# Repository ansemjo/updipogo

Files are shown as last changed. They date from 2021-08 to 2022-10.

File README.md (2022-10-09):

# updipogo

This was an idea to combine a tiny board with [pogo pins](https://aliexpress.com/item/1005002667659397.html) (spring-loaded probes) on one end and a cheap [CH340N USB-to-UART chip](https://lcsc.com/product-detail/USB-ICs_WCH-Jiangsu-Qin-Heng-CH340N_C2977777.html) on the other end, to build an [UPDI programmer](https://github.com/SpenceKonde/AVR-Guidance/blob/master/UPDI/jtag2updi.md). The idea stems from a [Pnoxi AVR-ISP Pogo](https://www.tindie.com/products/pnoxi/avr-isp-pogo-pin-adapter-2x3-idc2x3-pogo-254mm/), which I use for programming older AVRs.

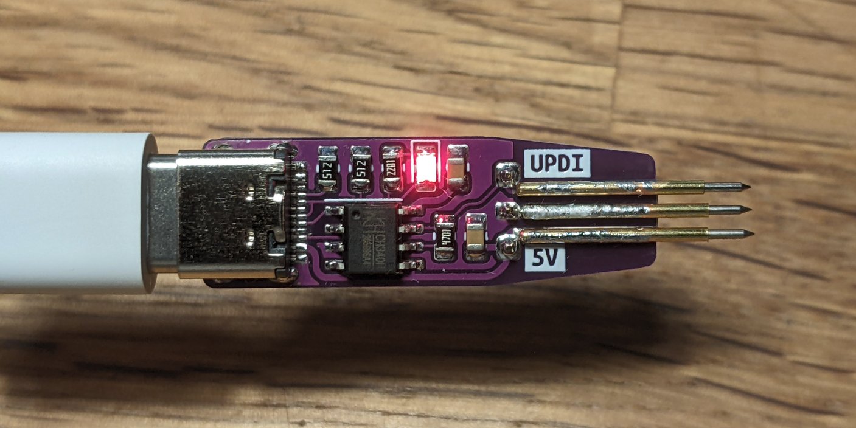
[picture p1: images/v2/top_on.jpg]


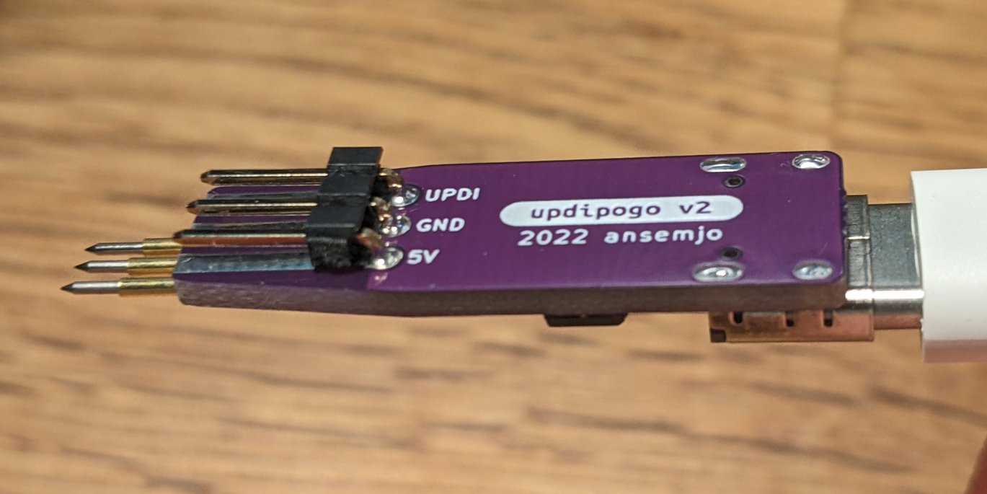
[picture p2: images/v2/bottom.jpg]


**Note:** It may be worthwhile to replace the 4.7 kΩ resistor with a diode instead. Or at least, use a smaller resistor in the range of 1–2 kΩ. [See errata](ERRATA.md#updipogo_v2).

### Programming Pads

The pogo footprint uses a somewhat dense pitch of 1.6 mm so that programming pads on future boards could require minimal space. The underside has footprints to add pins with standard 2.54 mm pitch or even a "normal" header, though.

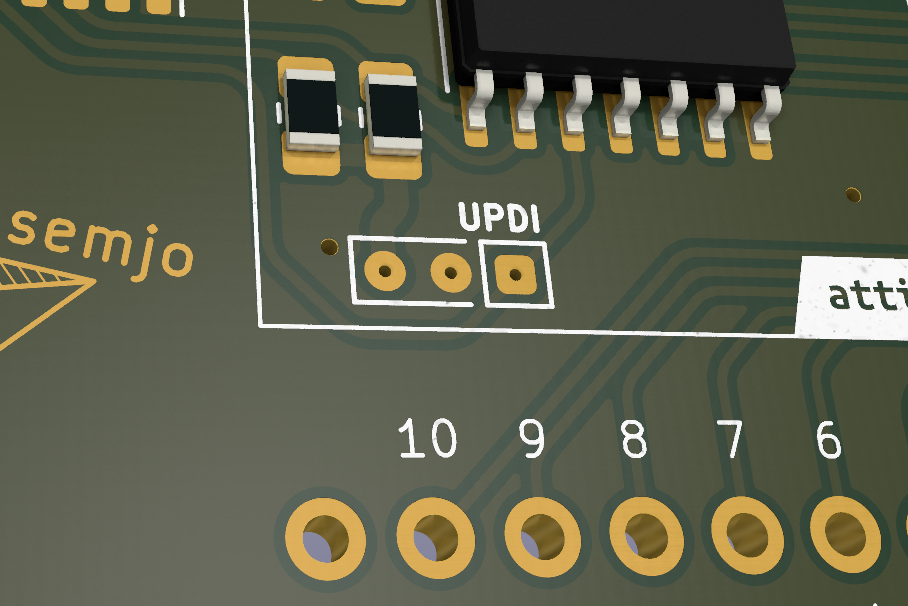
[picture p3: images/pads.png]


Add small 0.4 mm vias in the middle of the three programming pads if you can to give the spearhead tips something to fall into.

### Make Your Own

* Install [`kikit`](https://github.com/yaqwsx/KiKit)
* Run `make gerbers.zip`
* Order your PCBs
* Check the [interactive BOM](https://htmlpreview.github.io/?https://github.com/ansemjo/updipogo/blob/main/ibom.html) to see which part goes where

### Alternatives

[Stefan Wagner lists a lot of possible UPDI programmer alternatives](https://github.com/wagiminator/AVR-Programmer). Those include voltage switching, HV capable programmers and `jtag2updi`-compatible ones.

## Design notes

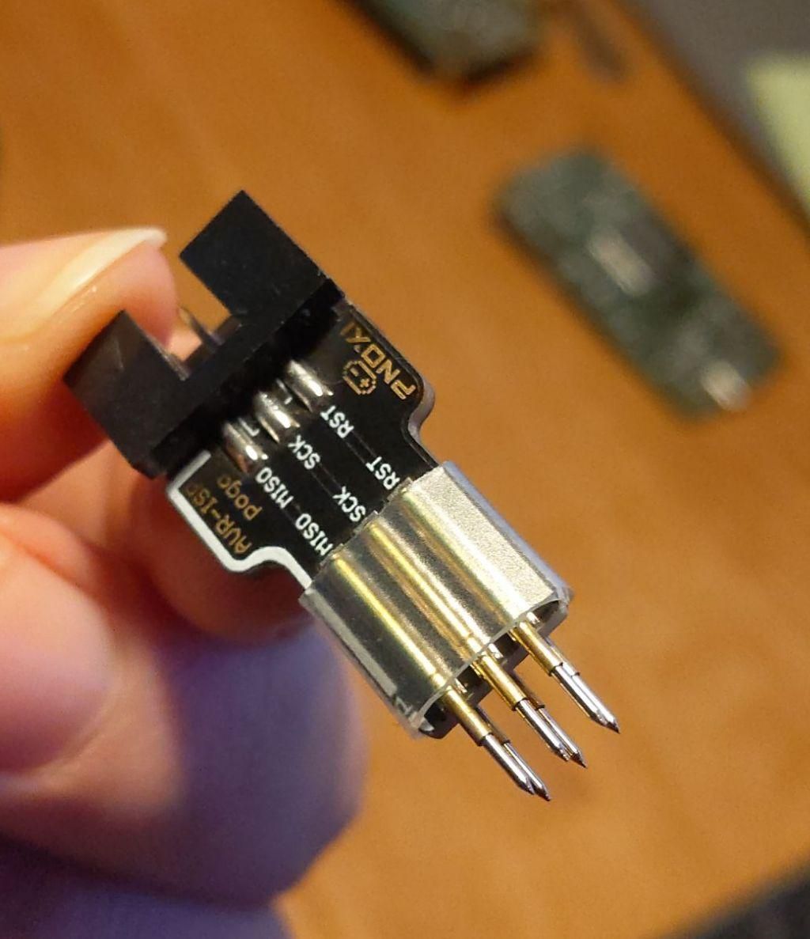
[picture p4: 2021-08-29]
images/pnoxi_pogo.jpeg

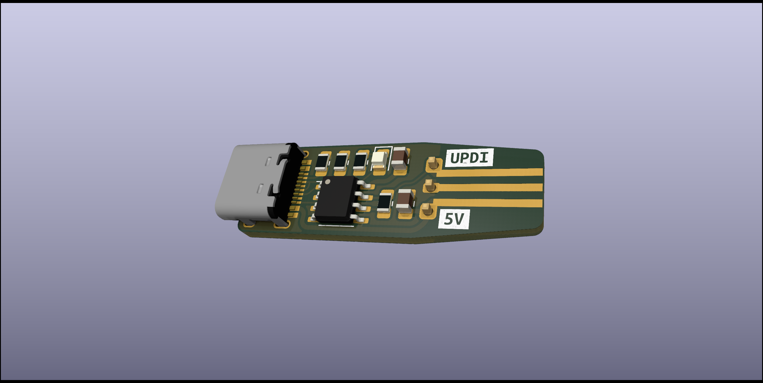
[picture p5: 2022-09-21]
images/v2/render.png

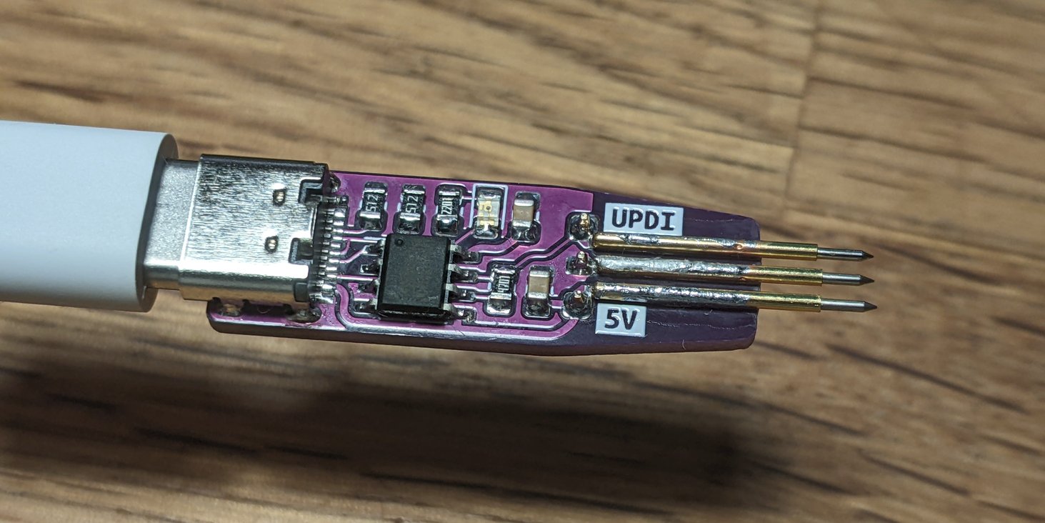
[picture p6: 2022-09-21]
images/v2/top_off.jpg

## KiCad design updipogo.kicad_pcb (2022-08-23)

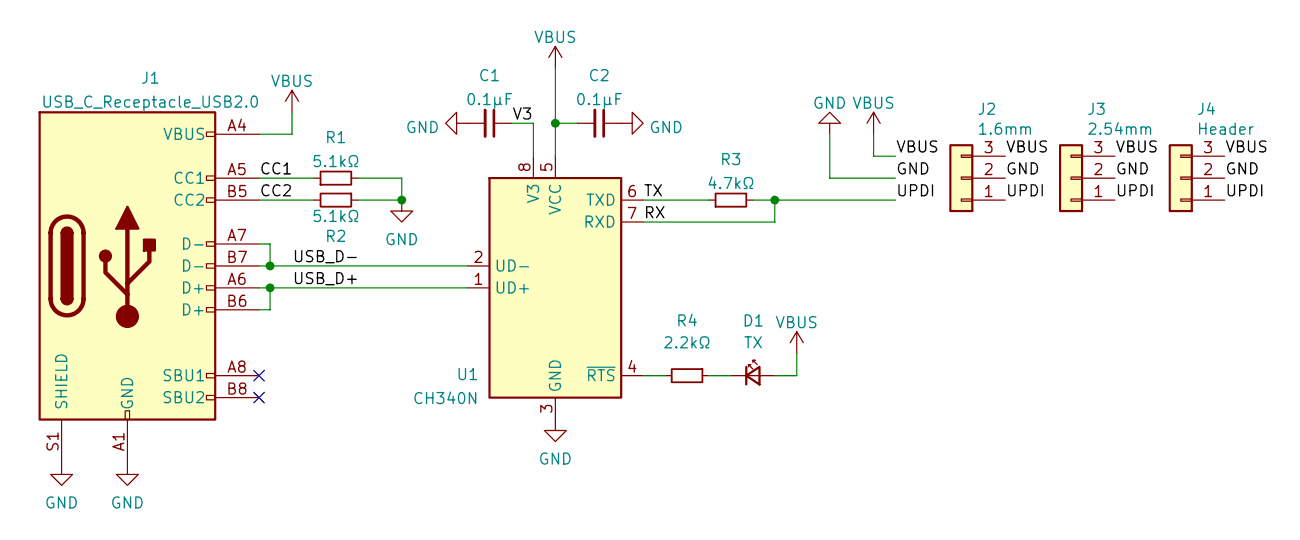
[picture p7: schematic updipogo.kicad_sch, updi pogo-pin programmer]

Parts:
C1, C2: 0.1µF; C_0805_2012Metric_Pad1.18x1.45mm_HandSolder
D1: TX; LED_0805_2012Metric_Pad1.15x1.40mm_HandSolder
J1: USB_C_Receptacle_USB2.0; USB_C_Receptacle_HRO_TYPE-C-31-M-12
J2: 1.6mm; PogoPins_1.6mm
J3: 2.54mm; PogoPins_2.54mm
J4: Header; CustomPinHeader_1x03_P2.54mm_Horizontal
R1, R2: 5.1kΩ; R_0805_2012Metric_Pad1.20x1.40mm_HandSolder
R3: 4.7kΩ; R_0805_2012Metric_Pad1.20x1.40mm_HandSolder
R4: 2.2kΩ; R_0805_2012Metric_Pad1.20x1.40mm_HandSolder
U1: CH340N; SOP-8_3.9x4.9mm_P1.27mm

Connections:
/CC1: J1.A5 (CC1), R1.1
/CC2: J1.B5 (CC2), R2.2
/RX: J2.1, J3.1, J4.1, R3.2, U1.7 (RXD)
/TX: R3.1, U1.6 (TXD)
/USB_D+: J1.A6 (D+), J1.B6 (D+), U1.1 (UD+)
/USB_D-: J1.A7 (D-), J1.B7 (D-), U1.2 (UD-)
/V3: C1.1, U1.8 (V3)
GND: C1.2, C2.1, J1.A1 (GND), J1.A12 (GND), J1.B1 (GND), J1.B12 (GND), J1.S1 (SHIELD), J2.2, J3.2, J4.2, R1.2, R2.1, U1.3 (GND)
unnamed: D1.1 (K), R4.1
unnamed: R4.2, U1.4 (~RTS)
VBUS: C2.2, D1.2 (A), J1.A4 (VBUS), J1.A9 (VBUS), J1.B4 (VBUS), J1.B9 (VBUS), J2.3, J3.3, J4.3, U1.5 (VCC)

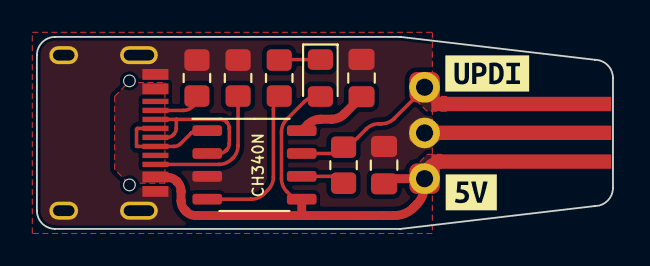
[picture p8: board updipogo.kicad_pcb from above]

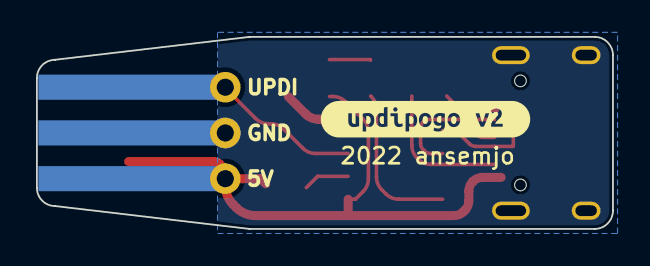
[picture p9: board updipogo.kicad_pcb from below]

Board: 2 copper layers, 32.0 x 10.7 mm, 15 parts (3 on the bottom side), 11 nets.

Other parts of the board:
kibuzzard-630501DC: G***; kibuzzard-630501DC
kibuzzard-6305024E: G***; kibuzzard-6305024E
kibuzzard-6305027C: G***; kibuzzard-6305027C

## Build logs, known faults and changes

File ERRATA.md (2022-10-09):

# Errata

## updipogo_v1

### Switched USB Polarity

On the first order I somehow mixed up USB `D+` and `D-`.

Cut the traces next to the serial chip and use thin enamelled wire to connect the receptacle correctly.

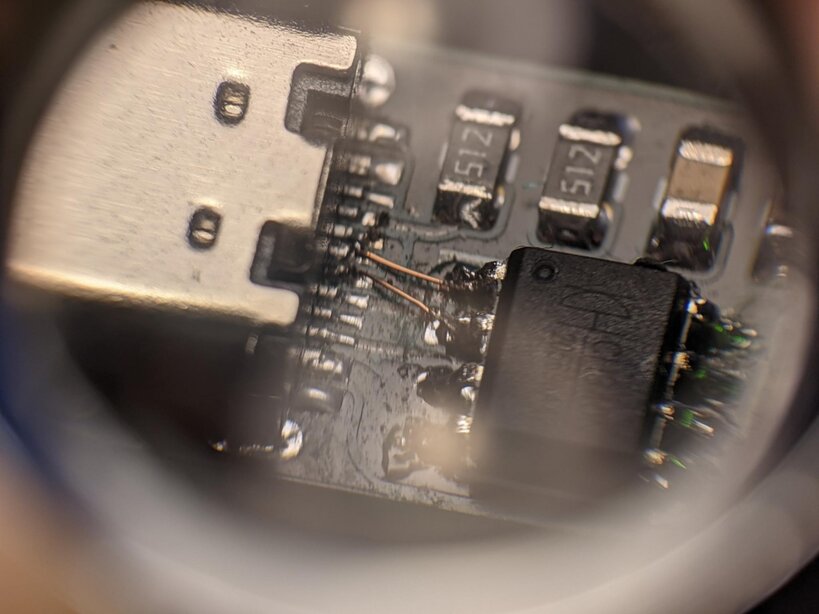
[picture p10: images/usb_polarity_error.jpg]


## updipogo_v2

### Replace the 4.7kΩ Resistor with a Diode

After soldering my v2 board I found that it doesn't reliably work with all my targets:

* `updiprog` wouldn't work at all?
* Soldering a "dummy" pogo plug and connecting `GND`, `VCC`, `TX`, `RX` and `RTS` to the pins of an FTDI adapter I found that an FT232R *can* "hear itself" (opening a console with no target connected and typing characters to see them echoed back) while an FT232H *could not*.
* `pymcuprog` works with an ATtiny414 but **not** with an AVR32DB48

Then I found [a lengthy manual on UPDI by SpenceKonde](https://github.com/SpenceKonde/AVR-Guidance/blob/master/UPDI/jtag2updi.md#connections), which also mentions different connection schemes with resistors and diodes. I shorted the resistor with tweezers and suddenly more of the above combinations worked.

I must admit, I do not fully grasp all the different combinations and since both target and programmer were designed by me, I *know* there are no external resistors in the UPDI path. So 4.7kΩ *should* have worked fine.

Anyway. I switched the resistor for a Shottky Diode (with the band towards `TX`) and started using `pymcuprog` exclusively. Now every combination works, both with the dummy plug and a fully populated updipogo_v2.

```
---------------+
            DTR|                           __________________
            Rx |------------,------------>| UPDI
  CH340N    Tx |-----|<|---'      .------>| Gnd   Target
            VCC|------------------------->| Vcc
            CTS|                 .`       |__________________
            Gnd|----------------'
---------------+
```

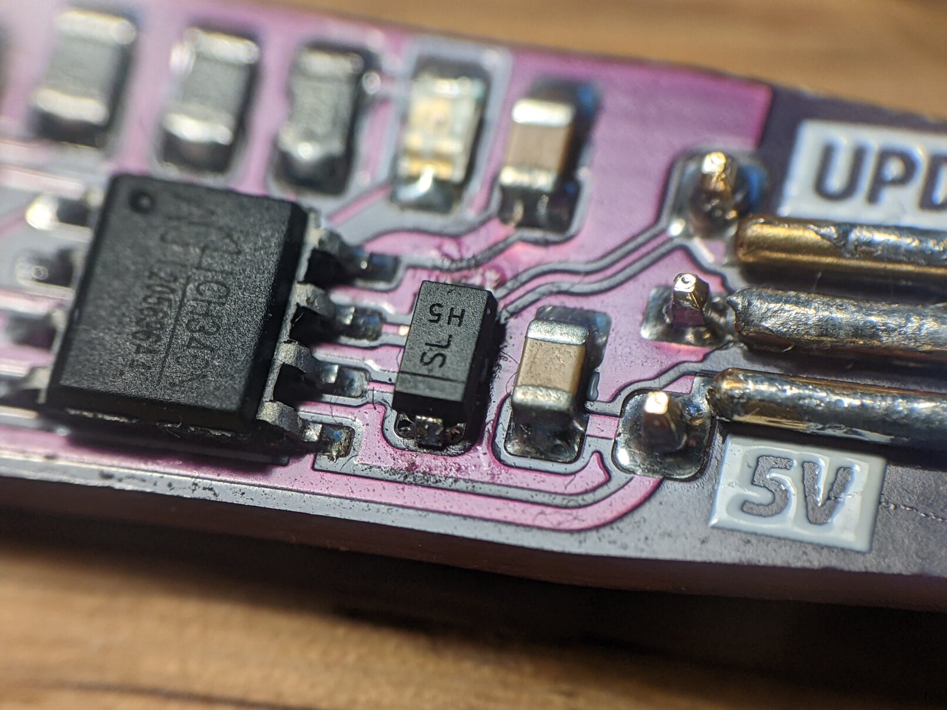
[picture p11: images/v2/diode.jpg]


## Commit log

2021-08-29 commit v1 of finished updipogo idea
    [updipogo.kicad_pcb, updipogo.kicad_sch, updipogo.sch]
2021-08-29 handcrafted 2x6 panel for jlcpcb
    [updipogo-panel.kicad_pcb, updipogo.kicad_pcb]
2021-09-18 change pinout of pogo pins to avoid rev. polarity danger
    [updipogo.kicad_sch]
2021-09-18 update pcb for new pinout
    [updipogo.kicad_pcb]
2021-09-19 reverse pin numbering and add footprint for pads
    updi pin is now pin 1 and is square / boxed-in on programming pads
    footprint
    [updipogo.kicad_pcb, updipogo.kicad_sch]
2021-09-19 change milling radius on tip narrowing
    [updipogo.kicad_pcb]
2021-09-29 fix usb polarity
    [updipogo.kicad_pcb, updipogo.kicad_sch]
2021-10-12 add note about lit-up LED
    [updipogo.kicad_pcb]
2022-08-23 connect led to RTS and update pcb layout a bit
    [updipogo.kicad_pcb, updipogo.kicad_sch]
2022-08-23 update footprints from library for new 3d model paths
    [updipogo.kicad_pcb]
2022-09-21 add interactive bom
2022-09-22 add errata about switching resistor for diode
2022-10-09 add image for v2 diode errata
